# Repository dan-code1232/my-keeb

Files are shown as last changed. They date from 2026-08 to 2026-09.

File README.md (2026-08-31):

# my-keeb
My keeb design and documents for the hack club keeb YSWS
TOTAL OF 32 hours learning and building

This YSWS was my first hack club project. I learnt about hackclub from online and I had a great time building and completeing this project. During theis project I made a custom keyboard with programmable macro keys and learnt 3d onshape design, soldering,kicad pcb design and also about different styles layouts and mounts of keyboards.My finished project was one that i am proud of and here it is!




##AND THE FINAL RENDER:::

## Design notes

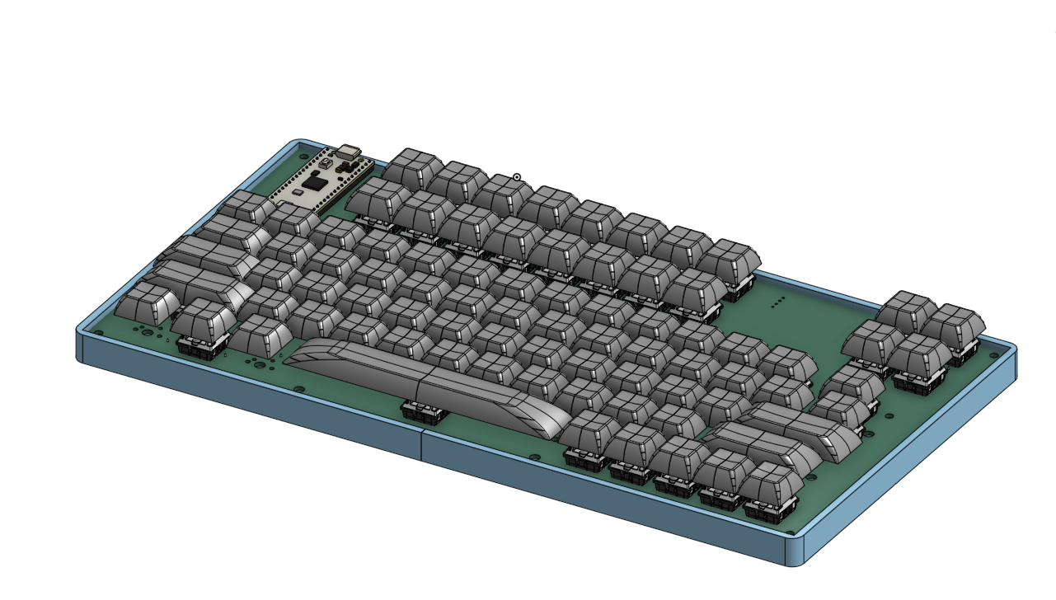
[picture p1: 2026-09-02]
Screenshot 2026-08-31 171520.png

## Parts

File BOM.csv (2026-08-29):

Part Name | Quantity | Link | Variant/Color | Price (GBP) | Price (USD)
JLCPCB PCB Manufacturing & Shipping | 1 | https://jlcpcb.com/ | White PCB | £29.00 | $40.00
0.91 inch OLED Screen | 1 | https://www.aliexpress.com/item/1005008640132638.html |  | £3.00 | $5.00
Tactile Switches | 2 sets | https://www.aliexpress.com/item/1005006382591392.html |  | £22.00 | $28.00
Raspberry Pi Pico | 1 | https://www.aliexpress.com/item/1005007525241877.html | Pico Type-C 1pc | £3.00 | $5.00
1N4148 Diodes | 70 | https://www.aliexpress.com/item/4000142272546.html |  | £2.00 | $4.00
Custom Keycaps | 1 | https://www.aliexpress.com/item/1005004613625285.html | HLB 143 | £19.00 | $25.00
White Stabilizers | 1 set | https://www.aliexpress.com/item/1005001840872635.html | White 7x2u 1x6.25u | £8.00 | $12.00
TOTAL |  |  |  | £86.00 | $119.00

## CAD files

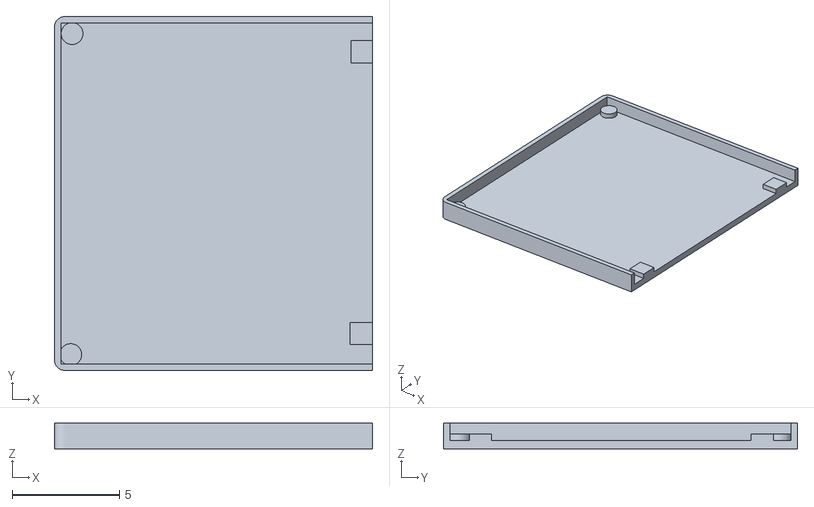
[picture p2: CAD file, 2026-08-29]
3d/Part1 of keeb keyboard.stl
14.9 x 16.5 x 1.20

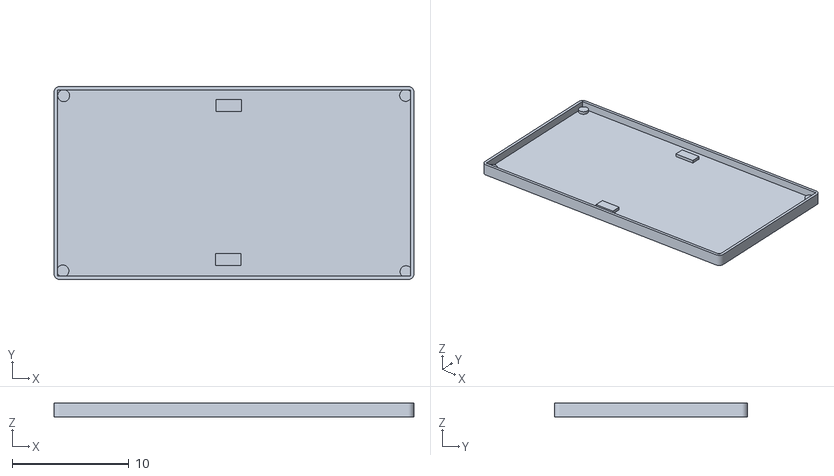
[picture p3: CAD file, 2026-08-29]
3d/Part 2 of keeb keyboard.stl
30.8 x 16.5 x 1.20

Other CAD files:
3d/keeb.step

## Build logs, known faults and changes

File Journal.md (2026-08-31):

# This is my keep journal of the development and learning process
# TOTAL OF 32 hours I hope it was worth it...

## Section 1 (2hrs 15 mins)
During this time I read through all the docs and planned my board. 

My initial designs are a 65 percent layout, with the Pi on the top left and an OLED screen on the top right:



I then made a matrix sketch to be sure of what I was going to design in KiCad.
Matrix-sketch:



## Section 2 (2 hours 30 mins) - the funnest part!
I updated my sketch to include better use of space and also to add macropad-style multi-function keys and volume buttons (I'm not going to include a rotary encoder). I then did a lot of research about mechanical keyboards, PCB design and how to make different keyboards sound different.



I then made a start on the process of transferring my design into the schematic editor with some mistakes that I found out later with numbering the rows and columns of the matrix:





And I wired the Pi:  



Then I found a problem with the wiring of each switch and had to redo it to find the problems.



After fixing this I ran ERC and got 27 errors, which consisted mainly of unconnected wires. This step was very tedious to fix all the errors systematically, but I completed it in the end:



## Section 3 (3.5 hours for the 1st arranging and bug fixing, 1.5 hours for the fixed run) - a lot of mistakes
After this I started arranging it on the PCB editor, however I got an error at first due to me opening the file in the wrong way:



After fixing this I continued arranging the PCB which took some time as there seemed to be too many keys at first... 



This turned out to be because in the very first switch I made, I accidentally put 2 switches on top of each other so I went back to the schematic again to delete all of the duplicates.



Finally I got it in rows but still there were too many keys if I wanted to have keys that weren't 1u. However I ignored this completely and continued.. which was a mistake. 

## Section 4: Layout Math & Routing (8 hrs approx for the keys, 1 hr for the OLED and fixes and fill) - I took a loooooong time
I am still working on getting the layout perfectly aligned. Placing the switches on the 19.05mm grid takes a lot of fiddling. I kept messing up the stagger by trying to drag the whole row, which ruined the right edge alignment thing and the grid that I used to place the switches also messed me up a lot. I eventually realized the trick is to just use the wide keys on the left (like 1.5u Tab and 1.75u Caps) to push the letters over so it looks good. I used the Move Exactly tool to get the math perfect so both the left and right edges are completely straight, as the keycap set which I wanted already had the suggestion.

I figured out how to do the wide keys (like the 2u Backspace and 6.25u Spacebar) by just centering a 1u switch and leaving a gap for the stabilizers. I also caught a massive mistake, I had not planned



Which took a long time..



and longer...



but I made it! and here is the finished work of art!



until I ran DRC and got a terrible amount of errors but then I got it down to only 



these



Routing the copper traces was a nightmare. I routed the columns on the front layer and the rows on the back layer. It looks a bit messy, but as long as it passes the DRC I am happy. The ground thing was super satisfying. I put the empty space with copper on both layers and hit B to fill it. I still had some GND errors because two pads are trapped on little copper islands. I am going to fix them later... hopefully.

I decided to go with a sandwich mount for the case, so I did not bother putting mounting holes on the board. The screws will just pass through the 5mm border around the edge. I exported the board as a STEP file and I am now moving over to Fusion 360 to start designing the 3D case. 

## Section 5: Case Design (1 hour for first run, 5 hrs for second run)
To do the case design I then opened up the online software Onshape. At first I played around a bit with the tools as I had never used the software before. After this I designed a simple 3D tray with a solid base which would act as my case. I then decided that if I printed a plate it might become stressed and crack over time so I changed my PCB to have mounting holes, and fixed some errors in the PCB at the same time. I then had to rebuild my case again with the new dimensions, which took a while, as the Onshape server kept lagging. Using the placement of the holes on the PCB I constructed several towers for the PCB to be able to screw into. After this I added fillets to all the corners to make it look better and then I used the assembly tab to make sure everything fit, which it did perfectly. Finally I used the split tool to split it in half. Overall I'm happy with my case design, but I think that it could be more detailed.

ZERO ERRORS!!!::::



my design:







## Section 6: Silkscreens (1 hour for choosing, 1.5 for putting it together and designing my logo)
For my silkscreens I decided to try to make the board really good as the JLCPCB company has a minimum order of 5. One of my favorite shows is Star Wars so I added a rebel logo and an imperial one on the opposite sides. Also I put a simple logo on with my initials in it.
Here's my logo:


And the silkscreen:


After this I put it into JLCPCB and played around with the settings until I was happy:


And the 3D editor was cool:

##Section 7:Firmware(45 mins):
I was scared at first by writing all the firmware but i found a template in RMK and copied it whilest changing everything like the rows and collms and keymap etc,which took less time then i was expecting.
## Section 8: BOM & Submission(4 hours approx)
finished compiling my  bom and getting all my files exported and zipped and everything.I spent a long time choosing parts and compatibilitu checking between them and making sure i had the cheapest yet best deals and good reliable parts. Im finally done!





THE END
TOTAL OF 32 hours

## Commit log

2026-08-04 Enhance Journal with design updates and images
    Updated Journal.md with new sketches and design process details, including images of the updated layout and schematic editor progress.
2026-08-12 Update Journal with wiring process and troubleshooting
    Documented the wiring process and errors encountered while working on the project. Added images to illustrate the steps taken and issues faced.
2026-08-26 Revise Journal.md with PCB design updates
    Updated Journal.md with detailed progress on PCB design and layout, including issues encountered and resolutions.
2026-08-28 Update layout math and routing section in Journal.md
    Revised layout description for switches and key placements, correcting mistakes and improving clarity.
2026-08-28 Add BOM file with components and pricing details
    [bom.csv]
2026-08-29 Revise BOM with variants and new components
    Updated BOM to include variant/color information and added PCB Mount Stabilizers.
    [bom.csv]
2026-08-29 Fix formatting and enhance clarity in Journal.md
    Corrected formatting and punctuation in various sections, improved clarity of section titles, and added details about the case design and silkscreens.
2026-08-29 Enhance Journal with silkscreen images and details
    Added images and descriptions for silkscreen designs and settings adjustments.
2026-08-29 Add parts list with pricing to BOM.csv
    Updated BOM.csv to include parts list and pricing for components used in the project.
    [BOM.csv]
2026-08-29 Revise component prices in BOM.csv
    Updated prices for components in BOM.csv.
    [BOM.csv]
2026-08-29 Update prices in bom.csv
    Updated the price of JLCPCB PCB Manufacturing and adjusted the total cost.
    [bom.csv]
2026-08-29 Modify BOM with new parts and updated prices
    Updated prices for several components and added new items.
    [bom.csv]
2026-08-29 Revise BOM with new parts and updated pricing
    Updated prices and added new components including Tactile Switches and White Stabilizers.
    [BOM.csv]
2026-08-30 Revise journal entries and update section details
    Updated journal entries with revised hours and details for each section, including case design and silkscreens. Added images and corrected formatting throughout.
2026-08-31 Update Journal with firmware and BOM sections
    Added sections for firmware and BOM submission details, including images.
2026-08-31 Rename ~MY KEEB PCB FIXED.kicad_pcb.lck to pcb/~MY KEEB PCB FIXED.kicad_pcb.lck
2026-08-31 Rename MY KEEB PCB FIXED.kicad_sch to pcb/MY KEEB PCB FIXED.kicad_sch
    [MY KEEB PCB FIXED.kicad_sch]
2026-08-31 Rename MY KEEB PCB FIXED.kicad_pcb to pcb/MY KEEB PCB FIXED.kicad_pcb
    [MY KEEB PCB FIXED.kicad_pcb]
2026-08-31 Rename Part 2 of keeb keyboard.stl to 3d/Part 2 of keeb keyboard.stl
    [Part 2 of keeb keyboard.stl]
2026-08-31 Rename Part1 of keeb keyboard.stl to 3d/Part1 of keeb keyboard.stl
    [Part1 of keeb keyboard.stl]
2026-08-31 Update lock file for MY KEEB PCB
2026-10-24 Update link for Tactile Switches in bom.csv
2026-10-24 Revise component prices and quantities in bom.csv
    Updated prices and quantities for several components in the BOM.
2026-10-29 Add keyboard assembly using Git LFS
2026-10-29 Rename Assembly 3.step to 3d/Assembly 3.step
2026-11-08 Fix matrix and OLED pin assignments
